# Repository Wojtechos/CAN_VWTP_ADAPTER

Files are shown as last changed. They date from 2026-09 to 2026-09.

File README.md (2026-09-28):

# CAN_VWTP_ADAPTER
Adapter is meant for older VW group cars (platform PQ 25) with VW TP 1.6 CAN protocol enabling them to communicate with newer radios which use VW TP 2.0 (RCD 330/340 etc.). <br> 
This bridge was specifically built for **pre-facelift Skoda Fabia 2**, so the format of messages and their IDs may differ from car to car (VW golf, polo etc.). <br>
**Note:** I had no access to VW TP 1.6 nor VW TP 2.0 protocols. This solution was built based on analysis of logs sniffed from my car's CAN bus and study of [decompiled code of chinese black box CAN converter](https://github.com/unemployable/Golf-Mk5-RCD330-CAN-Filter) and experiments with the message formats. 

### Components
- **Radio** - RCD340G
- **Car** - Skoda Fabia mk2 (2008)
- **MCU** - ESP32C3 super mini
- **CAN module** - MCP2515
- **Logic converter** - BSS138 (5V to 3.3V and vice versa)
- **Stepdown converter** - MP1584EN (12V to 5V)

## System Architecture Overview
```mermaid
  flowchart TD
    subgraph CAN Adapter
      MCU["ESP32C3"]
      LOGCONV1["Logic Converter"]
      LOGCONV2["Logic Converter"]
      CANMOD1["CAN module"]
      CANMOD2["CAN module"] 
    end
    subgraph CAN_IO
      RADIO(["CAR radio"])
      ECU(["CAR ecu"])
    end
    MCU --> LOGCONV1
    MCU --> LOGCONV2
    LOGCONV1 --> CANMOD1 
    LOGCONV2 --> CANMOD2
    ECU --> CANMOD1 
    CANMOD2 --> RADIO
    LOGCONV1 --> MCU
    LOGCONV2 --> MCU
    CANMOD1 --> LOGCONV1
    CANMOD2 --> LOGCONV2
```
## System Wiring
schema

## Functionality
Turns out there was only one type of message that needed to be altered and those were the messages from ECU (with ID `0x271`) which were resetting the sleep timer (position of the key in car's ignition). The car's ECU sends messages in format: 
```
<ID> <message>
```
where the message is in following format:
`<first byte> 0x80`.
Meaning the only the first byte contains the information about the position of the key.
- `00`: The key is inserted, the first position
- `03`: Second position of the key
- `07`: Third position of the key
- `87`: The engine is running

The message then looks like:
```0x271: 00 80```.

All that was needed was to send the same message with different ID. VW group cars often use either `0x2c3` or `0x575` and in this case the radio expects messages with ID `0x575`. 

From further analysis and experiments I found out that VW 1.6 and VW 2.0 are quite similar, because the radio understands messages about the state of the headlights out of the box. The message about the state of lights (which changes the brightness of the radio's diplay and turns on the illumination of the buttons) is sent with ID `0x635` in following format:
```0x635: 00 FF 00```
where only the first byte determines the intensity of the illumination, the other two bytes remain unchanged.  

The adapter enables the radio to understand messages about the current state of ignition. Now the radio:
1. Turns on when the ignition is turned on. 
2. Turns off when the key is removed from the switch box.
3. Bluetooth functionality is now enabled (not functional when the radio was not receiving correct messages).
4. The radio now **does not drain the car`s battery** while unused (standby mode) and does not turn itself off after 30 minutes.

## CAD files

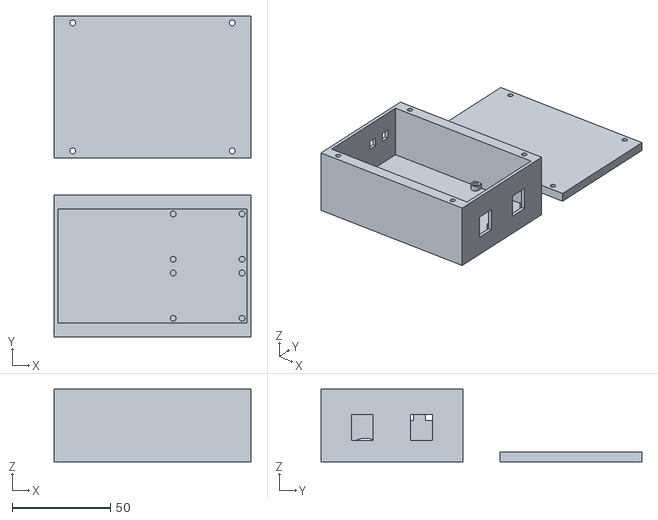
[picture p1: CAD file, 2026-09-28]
circuit_cover/CANbus cover.stl
100.0 x 163.0 x 37.0

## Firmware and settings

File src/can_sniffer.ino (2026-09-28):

#include <SPI.h>
#include <mcp_can.h>
#include "driver/gpio.h"

#define CAN_INIT_RETRY_CNT 10

// designed for ESP32C3 super mini pin layout
#define SCK_PIN       4
#define MISO_PIN      5
#define MOSI_PIN      6
#define CS_ECU_PIN    7
#define CS_RADIO_PIN  10
#define ECU_INT_PIN   0

MCP_CAN CAN_ECU(CS_ECU_PIN);
MCP_CAN CAN_RADIO(CS_RADIO_PIN);

volatile bool msg_incoming = false;

void IRAM_ATTR interrupt_handler() {
  msg_incoming = true;
}

bool init_can_module(MCP_CAN *can, unsigned int tries, unsigned int mcp_id) {
  // Initializes connection between MCU and given CAN module.
  // Params:
  //    &can - (MCP)CAN module 
  //    tries - number of retries
  //    mcp_id - id of can module for distinguishment in logs
  // Returns true if initializtion completed successfully, otherwise false is returned. 

  while (tries > 0) {
    if (can->begin(MCP_ANY, CAN_100KBPS, MCP_8MHZ) == CAN_OK) {
      Serial.println("MCP2515 " + String(mcp_id) + " initialised!");
      return true;
    } else {
      Serial.print("MCP2515 " + String(mcp_id) + " not found. Tries left: ");
      Serial.println(tries - 1);
      delay(500);
      tries--;
    }
  }

  return false; 
}

void setup() {
  Serial.begin(115200);
  delay(2000);

  gpio_set_drive_capability((gpio_num_t)SCK_PIN, GPIO_DRIVE_CAP_3);
  gpio_set_drive_capability((gpio_num_t)MOSI_PIN, GPIO_DRIVE_CAP_3);

  pinMode(ECU_INT_PIN, INPUT_PULLUP);
  pinMode(CS_ECU_PIN, OUTPUT);
  digitalWrite(CS_ECU_PIN, HIGH);
  pinMode(CS_RADIO_PIN, OUTPUT);
  digitalWrite(CS_RADIO_PIN, HIGH);

  SPI.begin(SCK_PIN, MISO_PIN, MOSI_PIN);
  
  Serial.println("Starting setup");
  bool can_ecu_ok = init_can_module(&CAN_ECU, CAN_INIT_RETRY_CNT, 1);
  bool can_radio_ok = init_can_module(&CAN_RADIO, CAN_INIT_RETRY_CNT, 2);

  if (!can_radio_ok || !can_ecu_ok) {
    Serial.println("ERROR: Could not connect to one or both CAN modules. Halting.");
    while (1) {
      delay(100); 
    }
  }

  CAN_RADIO.setMode(MCP_NORMAL);
  CAN_ECU.setMode(MCP_LISTENONLY);

  attachInterrupt(digitalPinToInterrupt(ECU_INT_PIN), interrupt_handler, FALLING);
  
  Serial.println("Setup complete. Waiting for message.");
}

void loop() {
  if (msg_incoming) {
    msg_incoming = false;

    while (CAN_ECU.checkReceive() == CAN_MSGAVAIL) {
    
      long unsigned int rx_id;
      unsigned char len = 0;
      unsigned char rx_buf[16];

      if (CAN_ECU.readMsgBuf(&rx_id, &len, rx_buf) == CAN_OK) {
            if (rx_id == 0x271) {   
          Serial.println("Sending msg");
          CAN_RADIO.sendMsgBuf(0x575, 0, len, rx_buf);
        }
        else { 
          byte is_ext = (rx_id & 0x80000000) ? 1 : 0;
          Serial.println("Sending msg");
          CAN_RADIO.sendMsgBuf(rx_id, is_ext, len, rx_buf);
        }
      }
    }
  }
}
